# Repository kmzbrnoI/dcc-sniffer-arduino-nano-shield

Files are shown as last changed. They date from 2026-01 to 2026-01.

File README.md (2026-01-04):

Arduino Nano DCC Sniffer shield
===============================

This repository contains:

1. schematic & PCB layout for Arduino Nano DCC Sniffer,
2. firmware for Arduino Nano to read packets,
3. software in python to read serial stream from Arduino Nano and store
   stream content in file.

Arduino Nano firmware is based on
[rudysmodelrailway project](https://rudysmodelrailway.wordpress.com/2015/10/23/dcc-sniffer-packet-analyser-with-arduino/).

Created by Jan Malina.

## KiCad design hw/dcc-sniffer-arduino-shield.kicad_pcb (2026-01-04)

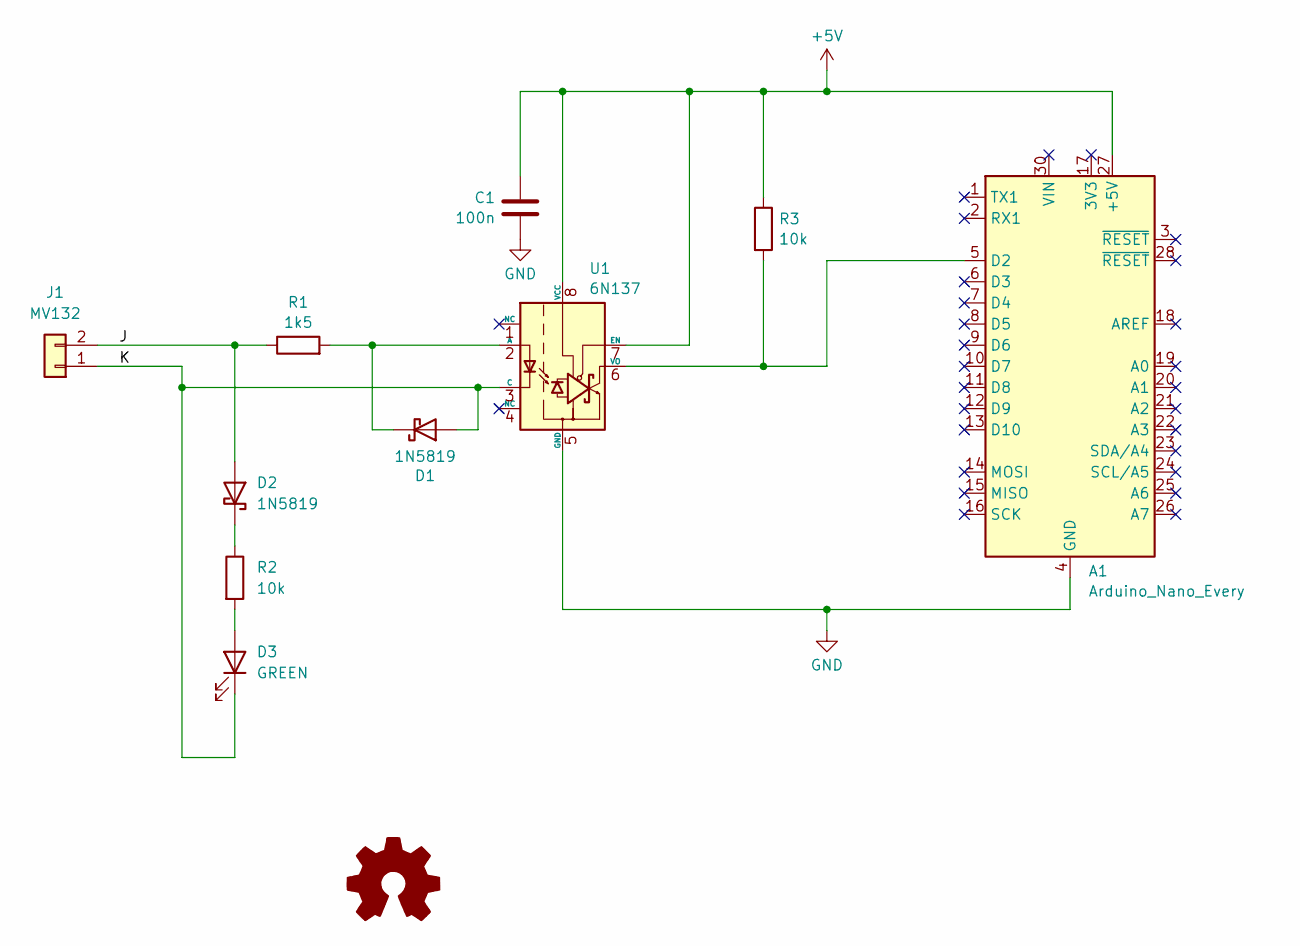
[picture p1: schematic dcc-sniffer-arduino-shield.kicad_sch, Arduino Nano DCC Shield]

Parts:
A1: Arduino_Nano_Every; Arduino_Nano
C1: 100n; C_0805_2012Metric_Pad1.18x1.45mm_HandSolder
D1, D2: 1N5819; D_SOD-123; LCSC C8598
D3: GREEN; LED_0805_2012Metric_Pad1.15x1.40mm_HandSolder
J1: MV132; TerminalBlock_4Ucon_1x02_P3.50mm_Horizontal
R1: 1k5; R_0805_2012Metric_Pad1.20x1.40mm_HandSolder
R2, R3: 10k; R_0805_2012Metric_Pad1.20x1.40mm_HandSolder
U1: 6N137; DIP-8_W7.62mm_LongPads

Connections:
+5V: A1.27 (+5V), C1.1, R3.1, U1.7 (EN), U1.8 (VCC)
/J: D2.2 (A), J1.2, R1.1
/K: D1.2 (A), D3.1 (K), J1.1, U1.3 (C)
GND: A1.4 (GND), A1.29 (GND), C1.2, U1.5 (GND)
unnamed: A1.5 (D2), R3.2, U1.6 (VO)
unnamed: D1.1 (K), R1.2, U1.2 (A)
unnamed: D2.1 (K), R2.1
unnamed: D3.2 (A), R2.2

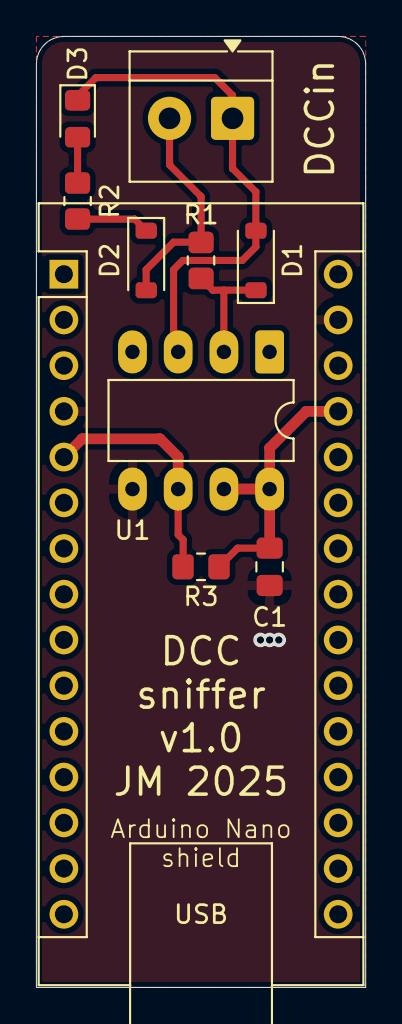
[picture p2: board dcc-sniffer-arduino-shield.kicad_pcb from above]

Board: 2 copper layers, 18.3 x 52.8 mm, 10 parts (0 on the bottom side), 8 nets.

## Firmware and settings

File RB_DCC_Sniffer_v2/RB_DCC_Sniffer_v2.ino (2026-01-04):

///////////////////////////////////////////////////////
//
// DCC packet analyze: Ruud Boer, October 2015
// DCC packet capture: Robin McKay, March 2014
// -------------------------------------------------------
// Version 2.0: Jürgen Winkler, March 2016
// - improve accessory decoder packet handling
// - improve detection of repeated = same packets
// - corrected display of on/off for basic accessory decoder packets
// - add hexdecimal output format for packets
// - packet output format may be selected using keyboard commands (bin,hex,both,none)
// - display of idle packet may be toggled using keyboard commands
// - add '?' help command displaying a list of available keyboard commands
// -------------------------------------------------------
//
// The DCC signal is detected on Arduino digital pin 2 - DCC signál se detekuje na pinu 2
//
// Set the Serial Monitor Baud Rate to 38400 !! Nastav rychlost Serial Monitoru na 38 400 baud!!
//
// Keyboard commands that can be sent via Serial Monitor:
// Klávesové příkazy, které mohou být zadány přes Serial Monitor:
//
// a = show accessory packets toggle - zobrazení paketů příslušenství (zapne/vypne)
// l = show locomotive packets toggle - zobrazení paketů lokomotivy (zapne/vypne)
// i = idle packet display on / off toggle - zobrazení idle paketů (zapne/vypne)
// h = hexadecimal output of packet data on / off toggle - zobrazení paketů hexadecimálně (zapne/vypne)
// b = binary output of packet data on / off toggle - zobrazení paketů binárně (zapne/vypne)
//
////////////////////////////////////////////////////////

#define TIMER_PRESCALER 64
#define DccBitTimerCount (F_CPU * 80L / TIMER_PRESCALER / 1000000L)
// 16000000 * 80 / 64 / 1000000 = 20; 20 x 4usecs = 80us

boolean packetEnd;
boolean preambleFound;

const byte bitBufSize = 50; // number of slots for bits
volatile byte bitBuffer[bitBufSize];
volatile byte bitBuffHead = 1;
volatile byte bitBuffTail = 0;

byte pktByteCount=0;
byte packetBytesCount;
byte preambleOneCount;
byte dccPacket[6]; // buffer to hold a packet
byte instrByte1;
byte decoderType; //0=Loc, 1=Acc
byte bufferCounter=0;
byte isDifferentPacket=0;
byte showLoc=1;
byte showAcc=1;

// --------------------added V2.0: begin ----------------
byte showIdle=0;
byte showBin=0;
byte showHex=1;
// --------------------added V2.0: end ----------------

unsigned int decoderAddress;

//========================

void getPacket() {
  preambleFound = false;
  packetEnd = false;
  packetBytesCount = 0;
  preambleOneCount = 0;
  while (! packetEnd) {
    if (preambleFound) getNextByte();
    else checkForPreamble();
  }
}

//========================

void checkForPreamble() {
   byte nextBit = getBit();
   if (nextBit == 1) preambleOneCount++;
   if (preambleOneCount < 10 && nextBit == 0) preambleOneCount = 0;
   if (preambleOneCount >= 10 && nextBit == 0) preambleFound = true;
}

//========================

void getNextByte() {
  byte newByte = 0;
  for (byte n = 0; n < 8; n++) newByte = (newByte << 1) + getBit();
  packetBytesCount ++;
  dccPacket[packetBytesCount] = newByte;
  dccPacket[0] = packetBytesCount;
  if (getBit() == 1) packetEnd = true;
}

//========================

byte getBit() {
  // gets the next bit from the bitBuffer
  // if the buffer is empty it will wait indefinitely for bits to arrive
  byte nbs = bitBuffHead;
  while (nbs == bitBuffHead) byte nbs = nextBitSlot(bitBuffTail); //Buffer empty
  bitBuffTail = nbs;
  return (bitBuffer[bitBuffTail]);
}

//========================

void beginBitDetection() {
  TCCR0A &= B11111100;
  attachInterrupt(0, startTimer, RISING);
}

//========================

void startTimer() {
  OCR0B = TCNT0 + DccBitTimerCount;
  TIMSK0 |= B00000100;
  TIFR0  |= B00000100;
}

//========================

ISR(TIMER0_COMPB_vect) {
  byte bitFound = ! ((PIND & B00000100) >> 2);
  TIMSK0 &= B11111011;
  byte nbs = nextBitSlot(bitBuffHead);
  if (nbs == bitBuffTail) return;
  else {
    bitBuffHead = nbs;
    bitBuffer[bitBuffHead] = bitFound;
  }
}

//========================

byte nextBitSlot(byte slot) {
  slot ++;
  if (slot >= bitBufSize) slot = 0;
  return(slot);
}

//========================

void printPacket() {
  // changed V2.0: show binary output is optional now
  if (showBin || showHex) {
    Serial.print(" Data");
  }
  if (showBin) {
    for (byte n=1; n<pktByteCount; n++) {
      Serial.print(" ");
      Serial.print(dccPacket[n],BIN);
    }
  }

  // --------------------added V2.0: begin ----------------
  // optionally show hexadecimal output now
  if (showHex) {
    Serial.print(" Hex");
    for (byte n=1; n<pktByteCount; n++) {
      Serial.print(" ");
      Serial.print(dccPacket[n],HEX);
    }
  }
  // --------------------added V2.0: end ----------------

  Serial.println();
}

//========================

void setup() {
  Serial.begin(115200); // 38400 when on DCC, 9600 when testing on 123Circuits !!!!!!!!!!!!!!!!!!!!!!!
  Serial.println(F("---"));
  Serial.println(F("DCC Packet Analyze V2.0 started"));
  Serial.println(F("---"));
  Serial.println(F("press ? for help"));      // added V2.0
  beginBitDetection(); //Uncomment this line when on DCC !!!!!!!!!!!!!!!!!!!!!!!!!!!!!!!!!!!!!!!!!!!!
  pinMode(13, OUTPUT);
  digitalWrite(13, LOW); //on board LED off
}

// added V2.0: start
void displayCV(byte mode, short cvAddress, byte cvValue) {
  switch(mode) {
    case 1: Serial.print("Verify "); break;
    case 2: Serial.print("Bit "); break;
    case 3: Serial.print("Write "); break;
    case 10: Serial.print("Bit write "); break;
    case 11: Serial.print("Bit verify "); break;
    default: Serial.print("reserved "); break;
  }
  Serial.print("Addr ");
  Serial.print(cvAddress);
  if (mode==2 || mode==10 || mode==11) {  // bit opertion
    Serial.print(" Bit ");
    Serial.print(dccPacket[pktByteCount-1]&B00000111);
    Serial.print("=");
    Serial.print((dccPacket[pktByteCount-1]&B00001000)>>3);
  } else {  // byte operation
    Serial.print(" Value ");
    Serial.print(cvValue);
  }
}
// added V2.0: end

//====================

void loop() {
  getPacket(); //Uncomment this line when on DCC !!!!!!!!!!!!!!!!!!!!!!!!!!!!!!!!!!!!!!!!!!!!!!!!!!!!
  byte speed;
  byte checksum = 0;
  unsigned long packetHash = 0;      // added V2.0

/* Dummy packet for test purposes. Comment when on DCC !!!!!!!!!!!!!!!!!!!!!!!!!!!!!!!!!!!!!!!!!!!!!!
// Loc 1782 CV Write 3 128
dccPacket[0]=6;
dccPacket[1]=B11000111;
dccPacket[2]=B01101110;
dccPacket[3]=B11101100;
dccPacket[4]=B00000011;
dccPacket[5]=B10000000;
dccPacket[6]=B11111111;
*/
  checkUserInput();    // changed v2.0: check user input anyway, also on idle packet and with packet having checksum error

  pktByteCount = dccPacket[0];
  if (!pktByteCount) return; // No new packet available

  for (byte n = 1; n <= pktByteCount; n++) checksum ^= dccPacket[n];
  //checksum=0; //Comment this line when on DCC !!!!!!!!!!!!!!!!!!!!!!!!!!!!!!!!!!!!!!!!!!!!!!!!!!!!!!!!!
  if (checksum) {
    Serial.println("Invalid checksum!");
    return; // Invalid Checksum
  }

  if (dccPacket[1]==B11111111) { //Idle packet
    if (showIdle)
      Serial.println("Idle ");
    return;
  }

  if (!bitRead(dccPacket[1],7)) { //bit7=0 -> Loc Decoder Short Address
    decoderAddress = dccPacket[1];
    instrByte1 = dccPacket[2];
    decoderType = 0;
  }
  else {
    if (bitRead(dccPacket[1],6)) { //bit7=1 AND bit6=1 -> Loc Decoder Long Address
      decoderAddress = 256 * (dccPacket[1] & B00111111) + dccPacket[2];
      instrByte1 = dccPacket[3];
      decoderType = 0;
    }
    else { //bit7=1 AND bit6=0 -> Accessory Decoder
      decoderAddress = dccPacket[1]&B00111111;
      instrByte1 = dccPacket[2];
      decoderType = 1;
    }
  }

  if (decoderType) { // Accessory Basic
    if (showAcc) {
      if (instrByte1&B10000000) { // Basic Accessory Decoder Packet Format
        decoderAddress = (((~instrByte1)&B01110000)<<2) + decoderAddress;
        byte port = (instrByte1&B00000110)>>1;
        Serial.print("Acc ");
        Serial.print((decoderAddress-1)*4 + port + 1);
        Serial.print(" ");
        Serial.print(decoderAddress);
        Serial.print(":");
        Serial.print(port);
        if (pktByteCount==3) {  // Basic Accessory Decoder Packet Format
          Serial.print(" output ");     // changes V2.0: bits 0 indicates which output of the pair is addresse
          Serial.print(bitRead(instrByte1,0));
          if (bitRead(instrByte1,3)) Serial.print(" On");  // changes V2.0 bits 3 is used to activate or deactivate the port
          else Serial.print(" Off");
        }
        // --------------------added V2.0: begin ----------------
        // handle decoder CV access
        else if (pktByteCount==5 && (dccPacket[2]&B10001100)==B00001100) {  // Accessory decoder Configuration variable Instruction - backward compatibility
          Serial.print(" CV ");
          int cvAddress = 1 + dccPacket[3] + (dccPacket[2]&B00000011)*256;
          byte cvValue = dccPacket[4];
          displayCV(3, cvAddress, cvValue);
        }
        else if (pktByteCount==6 && (dccPacket[3]&B11110000)==B11100000) {  // Accessory decoder Configuration variable Instruction
          Serial.print(" CV ");
          byte cvMode = (dccPacket[3]&B00001100)>>2;
          int cvAddress = 1 + dccPacket[4] + (dccPacket[3]&B00000011)*256;
          byte cvValue = dccPacket[5];
          displayCV(cvMode, cvAddress, cvValue);
        }
        else {
          Serial.print(" unknown ");
        }
        // --------------------added V2.0: end ----------------
      }
      else { // Accessory Extended NMRA spec is not clear about address and instruction format !!!
        Serial.print("Acc Ext ");
        decoderAddress = (decoderAddress<<5) + ((instrByte1&B01110000)>>2) + ((instrByte1&B00000110)>>1);
        Serial.print(decoderAddress);
        Serial.print(" Asp ");
        Serial.print(dccPacket[3],BIN);
      }
      printPacket();
    }
  }
  else { // Loc / Multi Function Decoder
    if (showLoc) {
      Serial.print("Loc ");
      Serial.print(decoderAddress);
      byte instructionType = instrByte1>>5;
      switch (instructionType) {

        case 0:
          Serial.print(" Control ");
        break;

        case 1: // Advanced Operations
          if (instrByte1==B00111111) { //128 speed steps
            if (bitRead(dccPacket[pktByteCount-1],7)) Serial.print(" Forw128 ");
            else Serial.print(" Rev128 ");
            byte speed = dccPacket[pktByteCount-1]&B01111111;
            if (!speed) Serial.print(" Stop ");
            else if (speed==1) Serial.print(" E-stop ");
            else Serial.print(speed-1);
          }
          else if (instrByte1==B00111110) { //Speed Restriction
          if (bitRead(dccPacket[pktByteCount-1],7)) Serial.print(" On ");
            else Serial.print(" Off ");
            Serial.print(dccPacket[pktByteCount-1])&B01111111;
          }
        break;

        case 2: // Reverse speed step
          speed = ((instrByte1&B00001111)<<1) - 3 + bitRead(instrByte1,4);
          if (speed==253 || speed==254) Serial.print(" Stop ");
          else if (speed==255 || speed==0) Serial.print(" E-Stop ");
          else {
            Serial.print(" Rev ");
            Serial.print(speed);
          }
        break;

        case 3: // Forward speed step
          speed = ((instrByte1&B00001111)<<1) - 3 + bitRead(instrByte1,4);
          if (speed==253 || speed==254) Serial.print(" Stop ");
          else if (speed==255 || speed==0) Serial.print(" E-Stop ");
          else {
            Serial.print(" Forw ");
            Serial.print(speed);
          }
        break;

        case 4: // Loc Function L-4-3-2-1
          Serial.print(" L F4-F1 ");
          Serial.print(instrByte1&B00011111,BIN);
        break;

        case 5: // Loc Function 8-7-6-5
          if (bitRead(instrByte1,4)) {
            Serial.print(" F8-F5 ");
            Serial.print(instrByte1&B00001111,BIN);
          }
          else { // Loc Function 12-11-10-9
            Serial.print(" F12-F9 ");
            Serial.print(instrByte1&B00001111,BIN);
          }
        break;

        case 6: // Future Expansions
          switch (instrByte1&B00011111) {
            case 0: // Binary State Control Instruction long form
              Serial.print(" BinStateLong ");
              Serial.print(256 * dccPacket[pktByteCount-1] + (dccPacket[pktByteCount-2]&B01111111));
              if bitRead(dccPacket[pktByteCount-2],7) Serial.print(" On ");
              else Serial.print(" Off ");
            break;
            case B00011101: // Binary State Control
              Serial.print(" BinStateShort ");
              Serial.print(dccPacket[pktByteCount-1]&B01111111);
              if bitRead(dccPacket[pktByteCount-1],7) Serial.print(" On ");
              else Serial.print(" Off ");
            break;
            case B00011110: // F13-F20 Function Control
              Serial.print(" F20-F13 ");
              Serial.print(dccPacket[pktByteCount-1],BIN);
            break;
            case B00011111: // F21-F28 Function Control
              Serial.print(" F28-F21 ");
              Serial.print(dccPacket[pktByteCount-1],BIN);
            break;
          }
        break;

        case 7:
          Serial.print(" CV ");
          if (instrByte1&B00010000) { // CV Short Form
            byte cvType=instrByte1&B00001111;
            switch (cvType) {
              case B00000010:
                Serial.print("23 ");
                Serial.print(dccPacket[pktByteCount-1]);
              break;
              case B00000011:
                Serial.print("24 ");
                Serial.print(dccPacket[pktByteCount-1]);
              break;
              case B00001001:
                Serial.print("Decoder Lock ");
                Serial.print(dccPacket[pktByteCount-1]);
              break;
            }
          }
          else { // CV Long Form
            int cvAddress = 256 * (instrByte1&B00000011) + dccPacket[pktByteCount-2] + 1;
            byte cvMode = (instrByte1&B00001100)>>2;
            byte cvData = dccPacket[pktByteCount-1];
            switch (cvMode) {
              case 1: // Verify Byte
              case 3: // Write Byte
                displayCV(cvMode, cvAddress, cvData);
              break;
              case 2: // Bit Write
                if (dccPacket[pktByteCount-2]&B00010000) displayCV(11, cvAddress, cvData); // bit verify
                else displayCV(11, cvAddress, cvData); // bit write
              break;
            }
          }
          break;

        default:
          Serial.print(" unknown instruction type ");
          Serial.println(instructionType);
        break;
      }
      printPacket();
    }
  }
}

// --------------------changed V2.0: begin ----------------
// refactor code - extrace own method for handling user input
// add handling of 'i', 'h', 'b' and '?' keys
// turn off interrupts while keyboard handling, sometimes serial.print last too long and the app crashes
// use F() macro to save memory in data memeory -> strings are now in program memory

void checkUserInput() {
  if (Serial.available()) {
    noInterrupts();            // changed V2: turn off interrupts, otherwise if serial.print last too long the app crashes
    Serial.println(" ");
    switch (Serial.read()) {
      case 97:
        if (showAcc) showAcc=0; else showAcc=1;
        Serial.print(F("show acc packets = "));
        Serial.println(showAcc);
      break;
      case 108:
        if (showLoc) showLoc=0; else showLoc=1;
        Serial.print(F("show loc packets = "));
        Serial.println(showLoc);
      break;
      case 105:
        if (showIdle) showIdle=0; else showIdle=1;
        Serial.print(F("show idle packets = "));
        Serial.println(showIdle);
      break;
      case 104:
        if (showHex) showHex=0; else showHex=1;
        Serial.print(F("show packet data in hexadezimal = "));
        Serial.println(showHex);
      break;
      case 98:
        if (showBin) showBin=0; else showBin=1;
        Serial.print(F("show packet data in binary = "));
        Serial.println(showBin);
      break;
      case 63: // ? show help
        Serial.println(F("Available keyboard commands:"));
        Serial.println(F("  a = accessory packets display on / off toggle"));
        Serial.println(F("  l = locomotive packets display on / off toggle"));
        Serial.println(F("  i = idle packet display on / off toggle"));
        Serial.println();
        Serial.println(F("  h = hexadecimal output of packet data on / off toggle"));
        Serial.println(F("  b = binary output of packet data on / off toggle"));
      }
    Serial.println(" ");
    interrupts();       // changed V2: turn interupts on again
  }
}
// --------------------changed V2.0: end ----------------

//=====================

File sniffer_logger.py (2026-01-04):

#!/usr/bin/env python3

import sys
import os
from datetime import datetime
import serial


def main() -> None:
    if len(sys.argv) < 2:
        sys.stderr.write(f'Usage: {sys.argv[0]} serial-device [logdir]\n')
        sys.exit(1)

    device = sys.argv[1]
    logdir = sys.argv[2] if len(sys.argv) > 2 else '.'

    ser = serial.Serial(device, 115200)

    while True:
        line = ser.readline().decode('ascii').strip()
        time = datetime.today().strftime('%H:%M:%S.%f')[:-3]
        filename = datetime.today().strftime('%Y-%m-%d') + '.log'
        with open(os.path.join(logdir, filename), 'a') as f:
            f.write(f'{time} {line}\n')
            print(f'{time} {line}')


if __name__ == '__main__':
    main()

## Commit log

2026-01-04 Add KiCad project & schematic.
    [dcc-sniffer-arduino-shield.kicad_pcb, dcc-sniffer-arduino-shield.kicad_sch]
2026-01-04 Route PCB.
    [dcc-sniffer-arduino-shield.kicad_pcb, dcc-sniffer-arduino-shield.kicad_sch]
2026-01-04 Add penguin graphic.
    [dcc-sniffer-arduino-shield.kicad_pcb]
2026-01-04 Mark DCC input pin D2.
    [dcc-sniffer-arduino-shield.kicad_pcb]
2026-01-04 Move PCB to 'hw' folder.
    [dcc-sniffer-arduino-shield.kicad_pcb, dcc-sniffer-arduino-shield.kicad_sch]
2026-01-04 Print packet when it arrives.
2026-01-04 Print 'unknown instruction type'.
2026-01-04 Do not print millis.

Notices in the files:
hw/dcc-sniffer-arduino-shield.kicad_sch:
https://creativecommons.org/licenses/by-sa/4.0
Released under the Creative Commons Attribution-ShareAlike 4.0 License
